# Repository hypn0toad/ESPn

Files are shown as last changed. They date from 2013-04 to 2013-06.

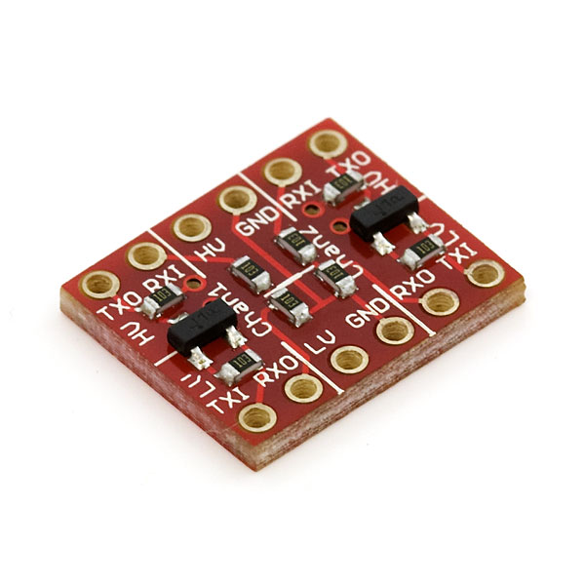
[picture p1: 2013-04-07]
docs/datasheets/Logic Level Converter Sparkfun/08745-03-L.jpg

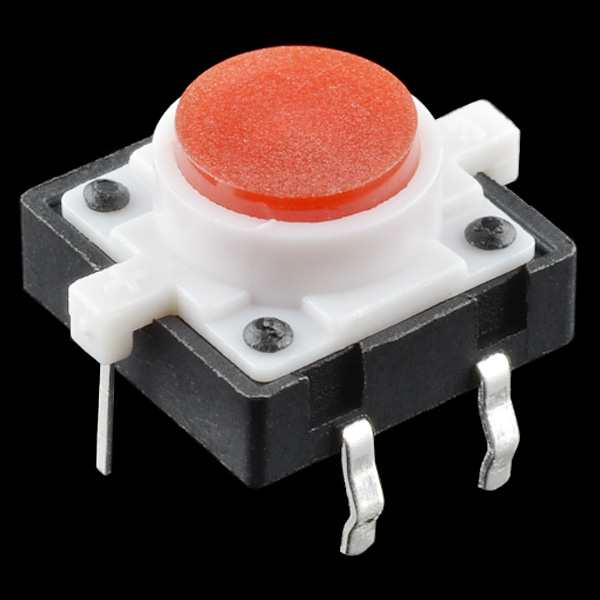
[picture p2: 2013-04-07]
docs/datasheets/LED Button/10442-01.jpg

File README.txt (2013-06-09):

This project consists of a multi platform communication device that was intended to be used as a gift / could be considered an art project. 

arduino_main/    = the main arduino code for the devices
arduino_slave/   = test code to be used in a prototype system. allows a serial interface on the PC (uart) to communicate through the arduino back and forth from an imp
imp/            = the imp code, needs to be loaded in the planner to both imps
docs/           = partslist/BOM, pinout reference, issue tracking (future ideas & bugs)
docs/datasheets = random datasheets for parts used in the design
docs/schematics = schematic and PWB for main board; schematic for logic level slave board

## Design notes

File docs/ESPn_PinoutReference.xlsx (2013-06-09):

Arduino | Description | Direction
0 | Rx, From Imp's TX | Input
1 | Tx, From Imp's RX | Output
2 | Red Button | Input
3 | Green Button | Input
4 | Standalone Gr LED | Output
5 | Online status (output from Imp, input to arduino, connects through Red Button LED) | Input
6 | Speaker | Output
7 | Green Button LED | Output
8 | Standalone Yellow LED | Output
9 | OLED MOSI | Output
10 | OLED CLK | Output
11 | OLED DC | Output
12 | OLED CS | Output
13 | OLED RESET | Output
14 | Switch 1 | Input
15 | Switch 5 | Input
16 | Switch 6 | Input
17 | Switch 7 | Input
Switch
1 | Arduino D14 (future use)
2 | Imp 8
3 | NC
4 | Imp 1
5 | Arduino D15 (future use)
6 | Arduino D16 (identity select)
7 | Arduino D17 (debug I/O)
8 | NC
Imp | Description | Direction
1 | Switch 4 (future use, but doesn't really work) | Input
2 | WiFi Status (ctrls LED and goes to Arduino) | Output
5 | UART Tx | Output
7 | UART Rx | Input
8 | Switch 2 (future use, works great) | Input
9 | NC / Pad

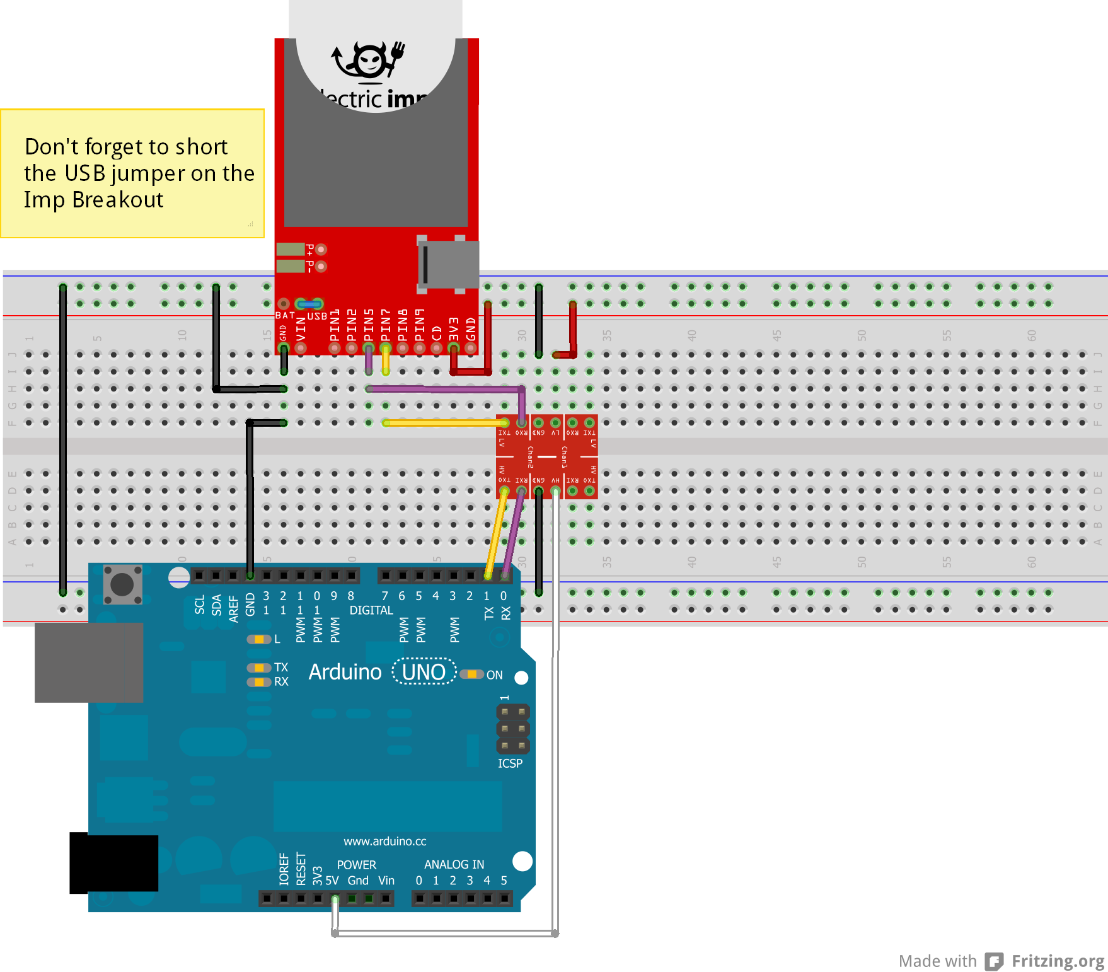
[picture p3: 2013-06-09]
docs/datasheets/Logic Level Converter Sparkfun/logic_level_connection-fritzing_schematic.png

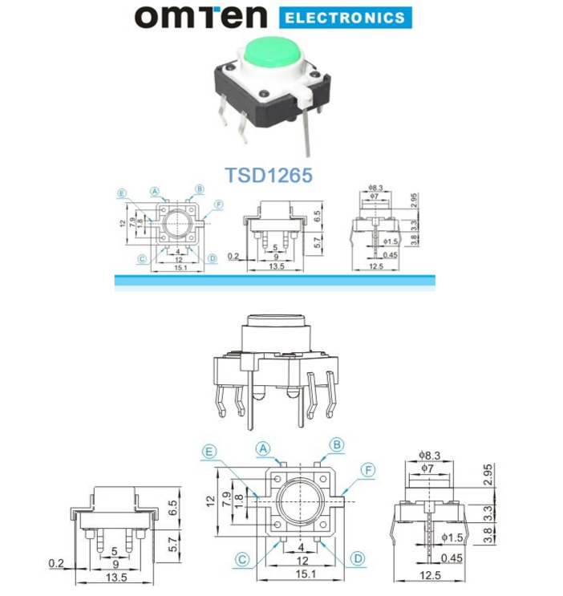
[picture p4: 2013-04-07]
docs/datasheets/LED Button/TSD1265.png

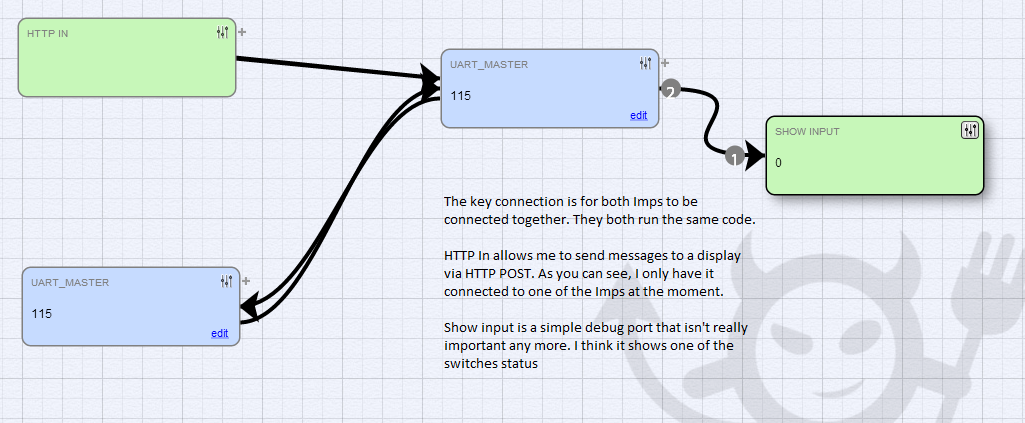
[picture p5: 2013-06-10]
imp/imp_planner.PNG

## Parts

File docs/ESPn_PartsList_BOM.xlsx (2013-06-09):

Item | Qty | Part Number | Mfg | Description | Distributor | Total Cost
1 | 1 | DEV-11114 | Sparkfun | Arduino Pro Mini 3.3V | Sparkfun | $10.00
2 | 1 | BOB-11400 | Sparkfun | Electric Imp Breakout | Sparkfun | $12.95
3 | 1 | WRL-11395 | Electric Imp | Electric Imp | Sparkfun | $30.00
4 | 1 | 938 | Adafruit | 1.3" OLED 128x64 Display | Adafruit | $24.50
5 | 1 | PS1240P02BT | TDK | Piezoelectric Buzzer | Adafruit | $1.50
6 | 1 | PRT-00119 | CUI | DC Jack Barrel Connector | Sparkfun | $1.25
7 | 1 | LD1117V33 | STMicro | 3.3V Regulator | Sparkfun | $1.95
8 | 2 | P975-ND | Unknown | 10uF Radial Lead Capacitor | Digikey | $0.46
9 | 1 | COM-08034 | China | DIP Switch Bank | Sparkfun | $1.50
10 | 1 | COM-10442 | China | Tactile LED PTH Button- Red | Sparkfun | $1.95
11 | 1 | COM-10440 | China | Tactile LED PTH Button- Green | Sparkfun | $1.95
12 | 2 | None | China | LEDs (one Gr one Ye) 5mm | Ebay - ics_shop | $0.17
13 | 4 | None | China | 0805 330ohm Resistors | Ebay - zjwhsd | $0.02
14 | 8 | None | China | 0805 10kohm Resistors | Ebay - zjwhsd | $0.03
15 | 2 | None | China | Tons Female and Male DC Headers | Ebay - ics_shop | $4.00

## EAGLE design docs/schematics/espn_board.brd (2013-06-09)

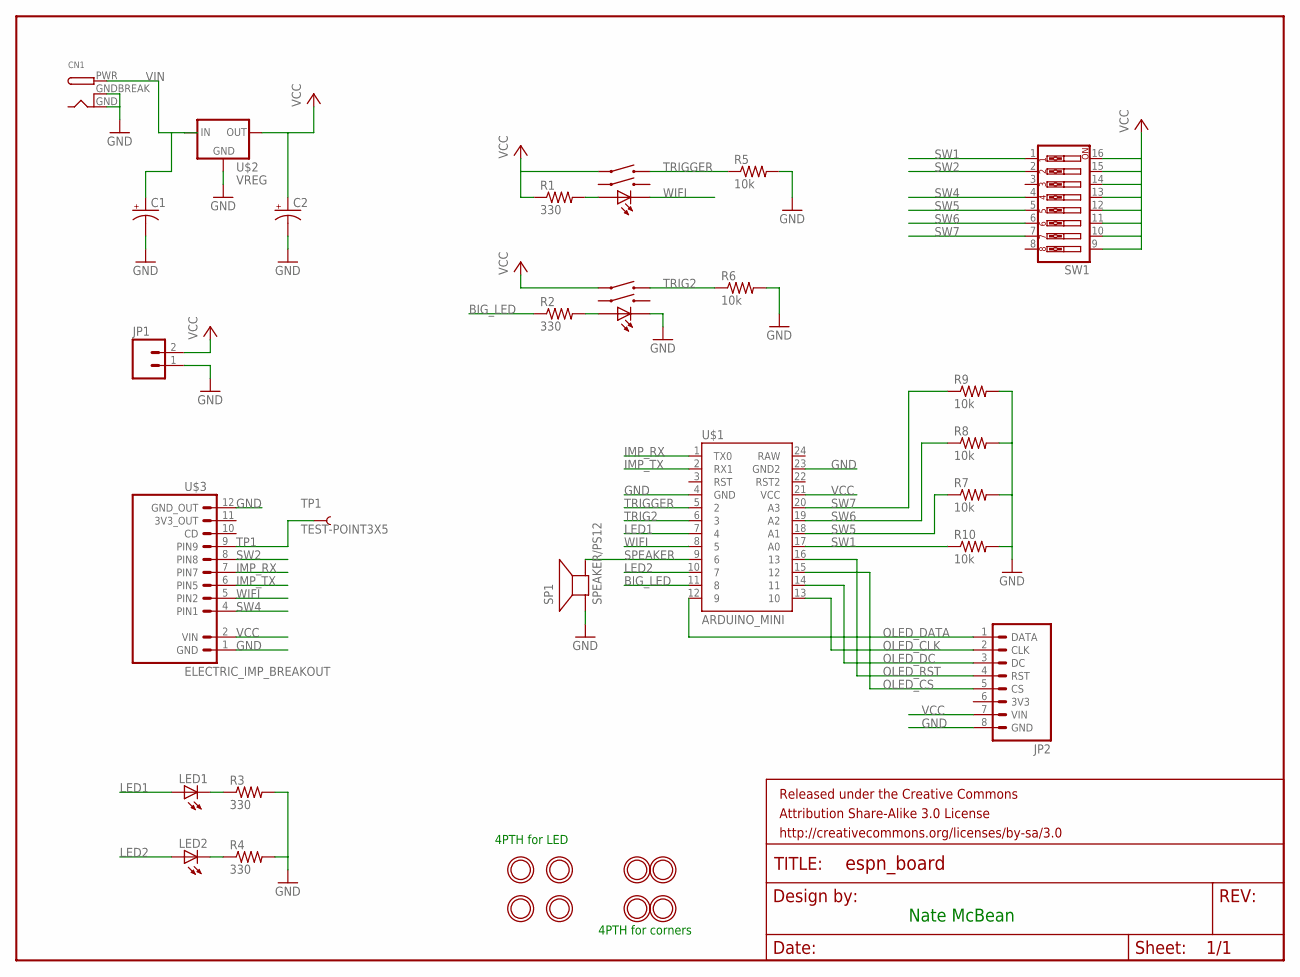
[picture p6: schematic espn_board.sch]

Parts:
ACK: LED_TACTILE_BUTTON
C1, C2: CAP_POLPTH2; CPOL-RADIAL-10UF-25V
CN1: DCBARRELPTH; DCJACK_2MM_PTH
FRAME1: FRAME-LETTER; CREATIVE_COMMONS
JP1: M02PTH; 1X02
JP2: OLED128X641X08; OLED_128X64
LED1, LED2: LED5MM
R1, R2, R3, R4: 330; R0805
R5, R6, R7, R8, R9, R10: 10k; R0805
SEND: LED_TACTILE_BUTTON
SP1: SPEAKER/PS12; PS12
SW1: SW_DIP-8; DIPSWITCH-08
TP1: TEST-POINT3X5; PAD.03X.05
U$1: ARDUINO_MINI
U$2: VREG; 78XXL
U$3: ELECTRIC_IMP_BREAKOUT
U$5, U$6, U$7, U$8, U$9, U$10, U$11, U$12: MOUNTINGHOLE2.5; MOUNTINGHOLE_2.5_PLATED

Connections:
BIG_LED: R2.1, U$1.11 (8)
GND: ACK.LEDC, C1.2 (-), C2.2 (-), CN1.GND, CN1.GNDBREAK, JP1.1, JP2.8 (GND), R3.2, R4.2, R5.2, R6.2, R7.2, R8.2, R9.2, R10.2, SP1.P$1 (+), U$1.4 (GND), U$1.23 (GND2), U$2.IN (GND), U$3.1 (GND), U$3.12 (GND_OUT)
IMP_RX: U$1.1 (TX0), U$3.7 (PIN7)
IMP_TX: U$1.2 (RX1), U$3.6 (PIN5)
LED1: LED1.A, U$1.7 (4)
LED2: LED2.A, U$1.10 (7)
unnamed: R1.2, SEND.LEDA
unnamed: ACK.LEDA, R2.2
unnamed: LED1.K (C), R3.1
unnamed: LED2.K (C), R4.1
OLED_CLK: JP2.2 (CLK), U$1.13 (10)
OLED_CS: JP2.5 (CS), U$1.15 (12)
OLED_DATA: JP2.1 (DATA), U$1.12 (9)
OLED_DC: JP2.3 (DC), U$1.14 (11)
OLED_RST: JP2.4 (RST), U$1.16 (13)
SPEAKER: SP1.P$2 (-), U$1.9 (6)
SW1: R10.1, SW1.1, U$1.17 (A0)
SW2: SW1.2, U$3.8 (PIN8)
SW4: SW1.4, U$3.4 (PIN1)
SW5: R7.1, SW1.5, U$1.18 (A1)
SW6: R8.1, SW1.6, U$1.19 (A2)
SW7: R9.1, SW1.7, U$1.20 (A3)
TP1: TP1.P$1, U$3.9 (PIN9)
TRIG2: ACK.SWA2, R6.1, U$1.6 (3)
TRIGGER: R5.1, SEND.SWA2, U$1.5 (2)
VCC: ACK.SWA1, C2.1 (+), JP1.2, JP2.7 (VIN), R1.1, SEND.SWA1, SW1.9, SW1.10, SW1.11, SW1.12, SW1.13, SW1.14, SW1.15, SW1.16, U$1.21 (VCC), U$2.GND (OUT), U$3.2 (VIN)
VIN: C1.1 (+), CN1.PWR, U$2.OUT (IN)
WIFI: SEND.LEDC, U$1.8 (5), U$3.5 (PIN2)

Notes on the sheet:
Nate McBean
4PTH for LED
4PTH for corners

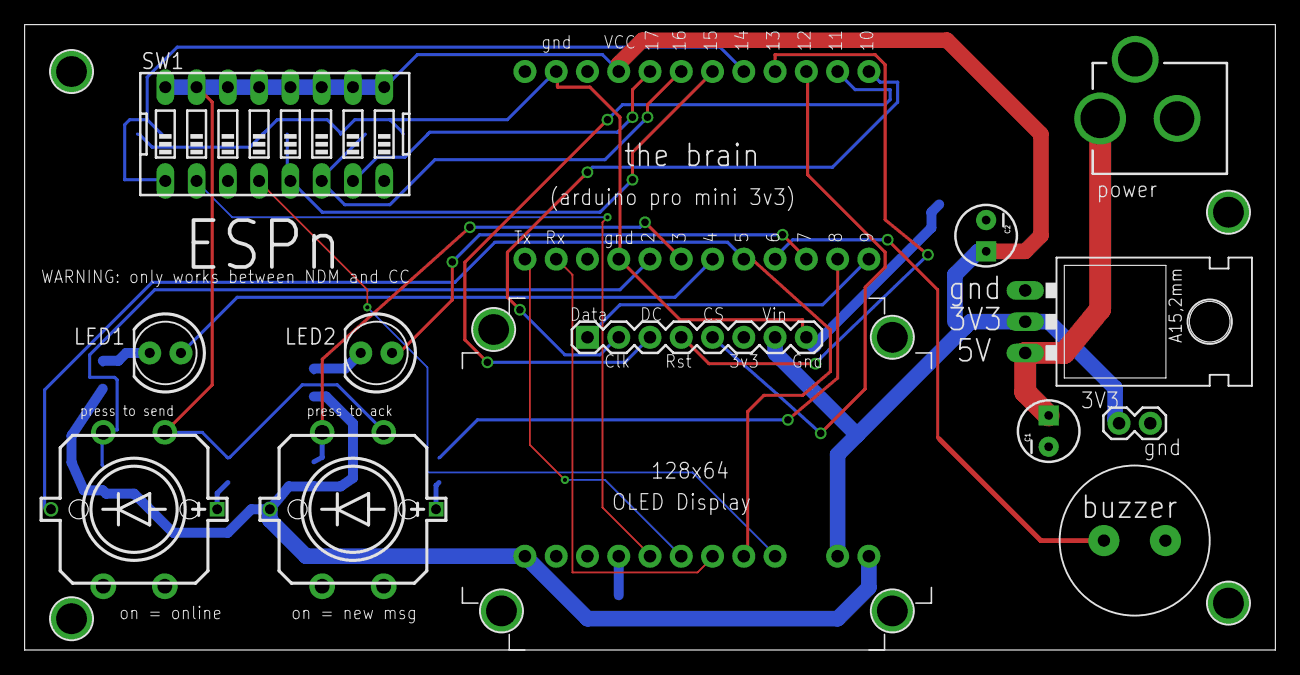
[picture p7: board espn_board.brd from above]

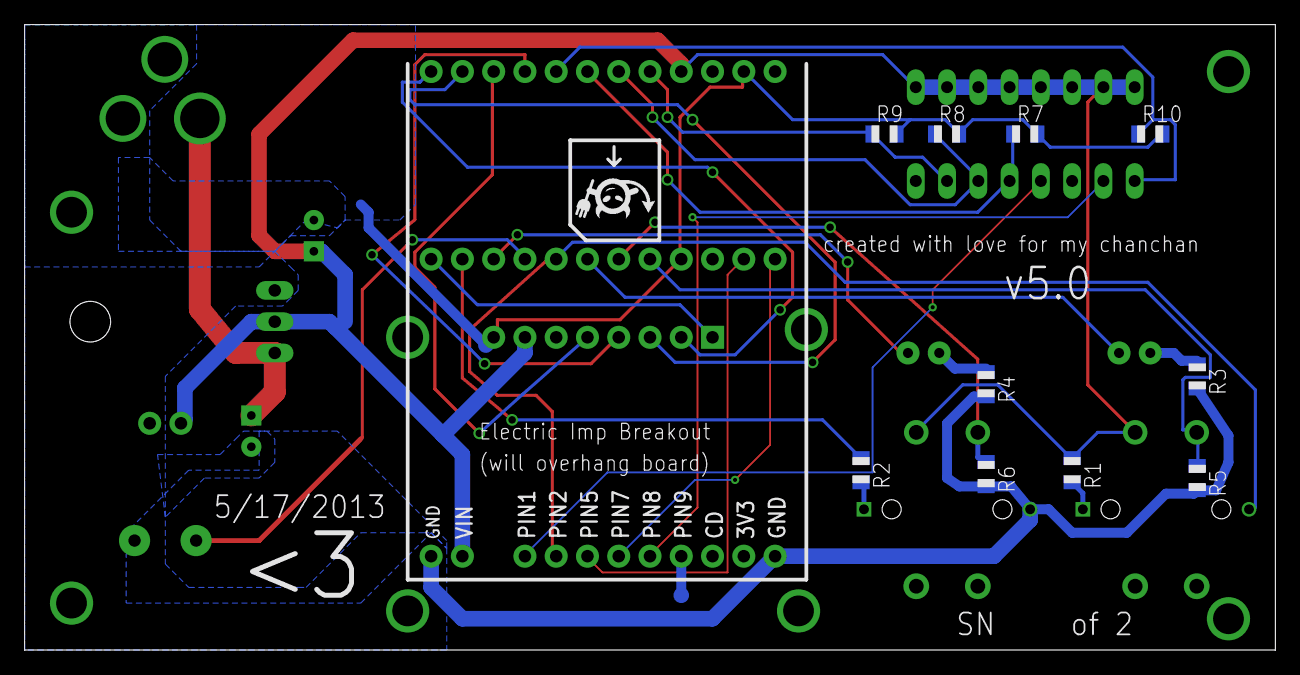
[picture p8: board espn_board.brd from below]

Board: 2 copper layers, 101.6 x 50.8 mm, 34 parts (12 on the bottom side), 28 nets.

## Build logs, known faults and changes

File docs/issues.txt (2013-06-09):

Here is a list of current issues with the design / possible improvements currently being considered. Really there weren't any huge issues, everything suprisingly worked without any sort of jumper wires or reprogramming.

PART SELECTION
- IMPROVEMENT: It would be nice to get rid of the April/Breakout Imp board. Not worth it to design custom for 2, but there arent many components that would be needed.

MECHANICAL DESIGN
- DEFECT: Holes for the OLED display are all incorrect. First off I borked the dimensions of the display and it unintentionally hangs off the bottom of the board. Secondly, the holes are the right size, but are in no way in the right space. It would be much better if these aligned. There needs to be some sort of support at the bottom. Instead of increasing board size, I would probably just not try to align the holes, and put a couple at the footer to add support for the display.

ELECTRCIAL DESIGN
- DEFECT: Red ButtonLED is much brighter than the Green ButtonLED. I suspect this is because of two reasons. First off, the Red LED is being driven via current sinking so it might be able to get more current. Secondly, I matched the resistances for the two LEDs even though they're different wavelengths. Different resistance values would probably also fix the mismatch but honestly it is more nitpicky and fine to deal with.
- DEFECT: Switch 4 doesn't correctly communicate with the Imp. I suspect this is a problem with the imp where that input isn't as flexible but the electronics are similar to that of switch 2, so I don't think its a big deal (especially since I'm not using the second switch).
- ANNOYANCE: It would be nice to have a power switch to disconnect all power from (1) the wall supply and (2) the arduino. Currently, I have to unplug the Imp when reprogramming the Arduino over the FTDI cable (it will try to draw too much current and will keep rebooting the board)

SOFTWARE
- DEFECT: TODO- fix handling of overflow for millis(). Right now I am betting on a power cycle every 40 days.
- IMPROVEMENT: use Progmem/EEPROM to store list of messages. That way I can have more variety and not run out of memory and get glitchy strings. I can also save settings between power cycles.
- IMPROVEMENT: expand to a second message type {} used for secondary string display to give variety. This would allow the internet/imp to do string management and would not make me have to deal with idiotic memory limitations of a microcontroller.
- IMPROVEMENT: loading bar at startup. didn't do this because of stupid string limitations
- IMPROVEMENT: change message triggering to interrupt functionality (thats why i picked pins 2 and 3 after all, but everything seemed to work with my lazy method)
- IMPROVEMENT: add phone interface
- IMPROVEMENT: Read receipt? with green button?
- IMPROVEMENT: Offline mode- as much as i like the electric imp, i have to be able to survive without the internet for futureproofing

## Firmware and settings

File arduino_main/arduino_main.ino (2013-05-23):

/*********************************************************************
  ESPn
  extrasensory perception via a network
  
  utilizing an arduino pro, a 128x64 OLED SPI display,
  an electric imp (and electric imp breakout board) and some accessories
 
  
  Revision Log
  Date       |Author     |Description
  -----------|-----------|-------------------------------------------
  03/31/2013  N. McBean   Initial Release- screen and piezo buzzer
  04/01/2013  N. McBean   Takes UART from the computer and displays
                            it on the OLED Display
  04/01/2013  N. McBean   Takes UART from the CLOUD (e-imp) and displays
                            it on the OLED Display O_o (matches with 
                            UART_Basic (V1) prog. pin5 imp to pin0 arduino
  04/02/2013  N. McBean   Added beep function. Added countown and 
                            rectangle bar drawing
  04/28/2013  N. McBean   Added specific pins for PWB. Tested board 
                            (all good!)
  05/05/2013  N. McBean   Changed communication protocol, now 
                            displays on screen when receive [], otherwise
                            handle each character individually.
                            Initial communication works with button press
                            TODO: debounce? needed? EDIT: nope. slow 'nuf
  05/06/2013  N. McBean   Changed string management to be char arrays.
                             i think my memory was getting garbage collected
                             and all messed up! boo! This works mostly though
                             bug- strings cant start with numbers. imp issue?
                             Also have LED indicator for long time since tx
                             Also have on screen reflection of ages. 
  05/07/2013  N. McBean   Changed LED1 & LED2 to display happy/stingy.
  05/08/2013  N. McBean   Ugh! Such limited memory. Todo: use PROGMEM
        v1.0                for now, reduce strings. 
  05/09/2013  N. McBean   Added some extra clearing triggers.
        v1.1

******************************************************************/

/*** library includes ***/
// OLED Display
#include <Wire.h>
#include <Adafruit_GFX.h>
#include <Adafruit_SSD1306.h>

/*** debug switches and settings ***/
String revID = "v1.1";
int  comm_frequency          = 21;    // how frequently we should ping the other device
int  screen_update_freq      = 1;     // how frequently should we update the screen
int  max_age_rx_comm         = 30;    // LED turns off when comm > this timeout
long age_for_low_tx          = 43200; // 12 hours since tx? complain!43200
long age_for_low_rx          = 43200; // 12 hours since rx? ensadden!


/*** pin definitions ***/
#define OLED_DC         11
#define OLED_CS         12
#define OLED_CLK        10
#define OLED_MOSI       9
#define OLED_RESET      13
#define SPEAKER_PIN     6
#define WIFI_STATUS_PIN 5

#define LED1_PIN    4
#define LED2_PIN    7
#define ACK_LED_PIN 8
#define TX_BUT_PIN  2
#define ACK_BUT_PIN 3
#define SW1_PIN     14
#define SW5_PIN     15
#define SW6_PIN     16
#define SW7_PIN     17

/*** global creations ***/
Adafruit_SSD1306 display(OLED_MOSI, OLED_CLK, OLED_DC, OLED_RESET, OLED_CS);

#if (SSD1306_LCDHEIGHT != 64)
#error("Height incorrect, please fix Adafruit_SSD1306.h!");
#endif

boolean stringComplete = false;  // whether the string is complete
unsigned long last_screen_update;

// internal stuff
boolean flash_led_status;
boolean debugio;
boolean current_identity; // 0 = c, 1 = n
boolean receiving_message;

// these boolean values are auto-updated and are based on timestamps and timeouts
boolean other_person_online, stingy_mode, happy_mode;

unsigned long last_tx_timestamp,      last_rx_timestamp;
unsigned long last_ping_tx_timestamp, last_ping_rx_timestamp;
unsigned long this_second;
char inputString[42];         // a string to hold incoming data 21 chars per line, 8 lines on size1
char oled_string[42];
int  inputString_index;

/*** initialization and setup ***/
void setup()   {                
  
  // by default, we'll generate the high voltage from the 3.3v line internally! (neat!)
  display.begin(SSD1306_SWITCHCAPVCC);
  display.clearDisplay();
  
  // initialize serial:
  Serial.begin(19200);
  //Serial.begin(9600);
  //while (!Serial) ;
  //Serial.println("Welcome!");
  
  // reserve 200 bytes for the inputString:
  inputString_index =0;
  
  last_screen_update = 0;
  //health = 100;
  this_second = 0;
  
  // setup communication
  last_tx_timestamp = 0;
  last_rx_timestamp = 0;
  last_ping_tx_timestamp = 0;
  last_ping_rx_timestamp = 0;
  other_person_online = false;
  stingy_mode = true;
  happy_mode  = false;
  
  // setup wifi status pin
  pinMode(WIFI_STATUS_PIN, INPUT);
  digitalWrite(WIFI_STATUS_PIN, 1);
  
  // setup other pins
  pinMode(LED1_PIN,    OUTPUT);
  pinMode(LED2_PIN,    OUTPUT);
  pinMode(ACK_LED_PIN, OUTPUT);
  pinMode(TX_BUT_PIN,  INPUT);
  pinMode(ACK_BUT_PIN, INPUT);
  pinMode(SW1_PIN,     INPUT);
  pinMode(SW5_PIN,     INPUT);
  pinMode(SW6_PIN,     INPUT);
  pinMode(SW7_PIN,     INPUT);  
  
  // initialize this to a value, it doesn't matter what it is
  flash_led_status  = true;
  // initial value is that we're not in the middle of a message.
  receiving_message = false;
  
  // read some startup values
  debugio = digitalRead(SW7_PIN);
  current_identity = digitalRead(SW6_PIN);

  // "demo mode" active
  if (digitalRead(SW5_PIN)) {
    // decrease thresholds for SHAME_LED and HAPPY_LED
    age_for_low_tx = 60;
    age_for_low_rx = 60;
  }
  
  // init done
  display.setTextSize(2);
  display.setTextColor(WHITE);
  display.setCursor(40,8);
  display.println("ESPn");
  
  display.setTextSize(1);
  display.setCursor(20,25);

  if ( current_identity ) {
    display.println("  Hello Nate!");     
  } else {
    display.println("Hello Christine!");     
  }

  display.setCursor(50,55);
  display.println(revID);
  display.display();

  // seed our random number generator (uses pin 5 which is NC)
  randomSeed(analogRead(5));

  //msg_class = 1;
  //msg_index = random(msg_health_low_len+1);
  
  delay(5000);
}

/*** never ending main loop ***/
// this does all of the main processing, but is specially crafted so that it should hopefully take 
// as close to zero time as possible. sure serial communication will eat up some time, but most events
// are essentially scheduled (checking timestamps), there should not be any delays in this code
void loop() {
  this_second = floor(millis()/1000);

  // first see if we've received any serial communication (this would be from the IMP).
  // this input will be decoded to see if it is part of a message, or just a command
  if(Serial.available() > 0)
  {
    // get the new byte (we receive one byte/character at a time)
    char inChar = (char)Serial.read();
    
    switch (inChar) {
      // check for starting character (this allows plaintext to be displayed)
      case '[':
        receiving_message = true;
        break;
      // check for ending character
      case  ']':
        stringComplete    = true;
        receiving_message = false;
        break;
      // any other character- advanced handle
      default:
        // if in the middle of a message, save the character
        if (receiving_message) { 
          inputString[inputString_index] = inChar;
          inputString_index++;
        // otherwise, decode the COMMAND character
        } else {
          switch (inChar) {
            // t = trigger = someone pressed the button on the other device
            case 't':
               //health = 100;
               last_rx_timestamp = this_second;
               beep();
               break; 
            // s = status = automatic ping from the other device
            case 's':
              last_ping_rx_timestamp = this_second;
              break;
            case 'x':
              last_ping_rx_timestamp = 0;
              break;
            case 'z':
              last_ping_tx_timestamp = 0;
              break;
          }
        } 
    }
  }

  // check if we should ping the server
  if ((this_second > last_ping_tx_timestamp + comm_frequency) | (last_ping_tx_timestamp == 0)) {
    Serial.print("s"); 
    last_ping_tx_timestamp = this_second;
  }
  
  // check for button press
  if (digitalRead(TX_BUT_PIN)) {
    last_tx_timestamp = this_second;
    beep();
    Serial.print("t"); 
  }  
  
  // if we just received a message, handle it.
  if (stringComplete) {
    //health = 100;
    for(int i = 0 ; i < inputString_index; i++) {
      oled_string[i] = inputString[i];
    }
    oled_string[inputString_index] = '\0';

    updateScreen();
    
    // maintenance for the next loop
    //Serial.println(inputString); 
    
    // clear the string:
    inputString_index = 0;
    stringComplete = false;
    
    beep();
  }

  // update the OLED display once a second (meh doesn't need to be faster)
  if(this_second > last_screen_update + screen_update_freq) {
    // if (health >= 5) {
    //   health -= 5; 
    // }
    updateScreen();
  }
}

/* Helper function, beeps 3 times */
void beep() {
  int delayms = 50;
  
  analogWrite(SPEAKER_PIN, 20);      // Almost any value can be used except 0 and 255
  delay(delayms);                    // wait for a delayms ms
  analogWrite(SPEAKER_PIN, 0);       // 0 turns it off
  delay(delayms);                    // wait for a delayms ms   
  
  analogWrite(SPEAKER_PIN, 20);      // Almost any value can be used except 0 and 255
  delay(delayms);                    // wait for a delayms ms
  analogWrite(SPEAKER_PIN, 0);       // 0 turns it off
  delay(delayms);                    // wait for a delayms ms 
  
  analogWrite(SPEAKER_PIN, 20);      // Almost any value can be used except 0 and 255
  delay(delayms);                    // wait for a delayms ms
  analogWrite(SPEAKER_PIN, 0);       // 0 turns it off
  delay(delayms);                    // wait for a delayms ms   
}

void updateScreen() {
  // first check wifi
  int wifi_not_connected = digitalRead(WIFI_STATUS_PIN);
  
  // temporarily comment out this code to save some valuable SRAM
  if( debugio ) {
    // // Blink some LEDs
    // digitalWrite(LED1_PIN, flash_led_status);
    // digitalWrite(LED2_PIN, flash_led_status);
    // digitalWrite(ACK_LED_PIN, flash_led_status);
    // flash_led_status = !flash_led_status;
    
    // display.clearDisplay();
    // display.setCursor(0,0);
    // display.print("Elapsed: ");
    // display.println(this_second);
    
    // display.print("Trig Button: ");
    // display.println(digitalRead(TX_BUT_PIN));
    // display.print("Ack Button : ");
    // display.println(digitalRead(ACK_BUT_PIN));   
    
    // display.print("SW1: ");
    // display.println(digitalRead(SW1_PIN));
    // display.print("SW5: ");
    // display.println(digitalRead(SW5_PIN));
    // display.print("SW6: ");
    // display.println(digitalRead(SW6_PIN));
    // display.print("SW7: ");
    // display.println(digitalRead(SW7_PIN));
  } else {
    // display it
    display.clearDisplay();
    display.setTextSize(1);
    

    // first line = wifi status
    display.setCursor(115,0);
    if(wifi_not_connected) {
      display.print(":(");
    } else if (other_person_online) {
      display.print("XD");
    } else {
      display.print(":)");
    }

    display.setCursor(0,9);
    // first line = love age
    if(last_rx_timestamp != 0) {
      unsigned long delta = this_second-last_rx_timestamp;
      display.print("Last rx ");
      if( delta > 3600) {
        display.print(delta/3600);
        display.print('h');
      } else if (delta > 60) {
        display.print(delta/60);
        display.print('m');
      } else {
        display.print(delta);
        display.print('s');
      }
      display.println(" ago");
    }

    // second line = last sighting (optional) 
    // IF haven't seen yet- complain!
    // IF haven't seen recently- display last sighting!
    // else shh, the progress bar shows this information
    if(last_ping_rx_timestamp == 0) {
      display.print("Can't find ");
      display.println(current_identity?"chanchan!":"maido!");
    } else if (!other_person_online) {
        display.print("Saw ");
        display.print(current_identity?"her ":"him ");
        display.print(this_second-last_ping_rx_timestamp);
        display.println("s ago!");
    } else {
      if(happy_mode && stingy_mode && other_person_online ) {
        display.println("All good-Share love!");
      } else if (happy_mode) {
        display.println("Sensing ample love!");
      } else {
        display.println("Fuel nearing empty!");
      }
    }

    // 4th line message if there is one
    display.setCursor(0,40);
    display.println(oled_string);
    
    display.drawRect(5,59,118,5,WHITE);
    
    //float width = 1.18*health;
    float rxhealth;
    if(last_ping_rx_timestamp==0) {
      rxhealth = 0;
    } else {
      float rxdiff, rxmax, rxdiv;
      rxdiff = this_second-last_ping_rx_timestamp;
      rxmax  = max_age_rx_comm;
      rxdiv = rxdiff/rxmax;
      rxhealth = 118 * (1-rxdiv);
    }
    float width = rxhealth;
    display.fillRect(5,59,ceil(width),5,WHITE);
  }
    
  display.display();
  last_screen_update = this_second;

  /*** update boolean values ***/
  // update the OTHER PERSON PRESENT indicator
  if ( (this_second > last_ping_rx_timestamp + max_age_rx_comm) || (last_ping_rx_timestamp == 0)) { 
    other_person_online = false;
    digitalWrite(ACK_LED_PIN,0);
  } else {
    other_person_online = true;
    digitalWrite(ACK_LED_PIN,1);
  }

  // initiate SHAME_LED when haven't txed in TX_AGE
  if( (last_tx_timestamp == 0) || this_second > (last_tx_timestamp + age_for_low_tx)) {
    stingy_mode = true;  
    digitalWrite(LED2_PIN,1);
  } else {
    stingy_mode = false;
    digitalWrite(LED2_PIN,0);
  }

  
  // initiate HAPPY_LED when have rx'ed in RX_AGE
  if ((last_rx_timestamp == 0) || this_second > (last_rx_timestamp + age_for_low_rx)) {
    happy_mode = false;
    digitalWrite(LED1_PIN,0);
  } else {
    happy_mode = true;
    digitalWrite(LED1_PIN,1);
  }  
}

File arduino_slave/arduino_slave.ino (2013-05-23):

/*********************************************************************
  ESPn
  extrasensory perception via a network
  
  utilizing an arduino pro, a 128x64 OLED SPI display,
  an electric imp (and electric imp breakout board) and some accessories
 
  
  Revision Log
  Date       |Author     |Description
  -----------|-----------|-------------------------------------------
  04/05/2013  N. McBean   Initial Release based on other code
                            this code will interact with the serial
                            terminal. Used as a test board to send 
                            and receive signals from the other board
  04/07/2013 N. McBean    Will receive messages from the imp and 
                            print them in the serial console. Will
                            send messages to the imp when typed.
******************************************************************/

/*** library includes ***/
// OLED Display
#include <Wire.h>
#include <Adafruit_GFX.h>
#include <Adafruit_SSD1306.h>

/*** pin definitions ***/
#define OLED_DC     11
#define OLED_CS     12
#define OLED_CLK    10
#define OLED_MOSI   9
#define OLED_RESET  13
#define SPEAKER_PIN 6
#define TRIGGER_PIN 2

/*** global creations ***/
Adafruit_SSD1306 display(OLED_MOSI, OLED_CLK, OLED_DC, OLED_RESET, OLED_CS);

#if (SSD1306_LCDHEIGHT != 64)
#error("Height incorrect, please fix Adafruit_SSD1306.h!");
#endif

String inputString = "";         // a string to hold incoming data 21 chars per line, 8 lines on size1
String oled_string = "";
boolean stringComplete = false;  // whether the string is complete
unsigned long last_screen_update;
unsigned long last_communication_timestamp;
unsigned long last_communication_age;
String console_input = "";
boolean consoleComplete = false;
int health;

volatile int trigger_button_pushed = 0;
unsigned long last_trigger;


/*** initialization and setup ***/
void setup()   {                
  /**********************************************************************************/
  /* setup display */
  display.begin(SSD1306_SWITCHCAPVCC);
  display.clearDisplay();
  display.setTextSize(1);
  display.setTextColor(WHITE);
  display.setCursor(0,0);
  display.println("Powering up...");
  display.display();

  /**********************************************************************************/  
  /* setup serial */
  Serial1.begin(19200);
  Serial.begin(9600);
  //while (!Serial) ;
  Serial.println("Welcome!");
  
  // reserve 200 bytes for the inputString:
  inputString.reserve(200);
  oled_string.reserve(200);
  console_input.reserve(200);
  
  last_screen_update = 0;
  health = 100; 

  /**********************************************************************************/
  /* send a dummy message to the imp */
  Serial1.println("Auto comm from slave imp...,");
  
  /**********************************************************************************/
  /* setup trigger button */
  trigger_button_pushed = 0;
  pinMode(TRIGGER_PIN, OUTPUT);
  // this needs to be 0 because the first (0th) interrupt is on pin 2
  // THE STUPID LEONARDO MESSED UP NUMBERING- pin 3 = int 0
  // use PIN3 on the leonardo. use PIN2 on the pro ugh.
  attachInterrupt(0,trigger_push, RISING);
  last_trigger =0;  
}

// we hit the trigger! don't do serial operations in here. get out ASAP
// (from the documentation "Inside the attached function, delay() won't work and the 
// value returned by millis() will not increment. Serial data received while in the 
// function may be lost. You should declare as volatile any variables that you modify 
// within the attached function.

void trigger_push () {
  trigger_button_pushed = 1; 
}

/*** never ending main loop ***/
void loop() {
  
  // read from the console
  if(Serial.available() > 0)
  {
    char inChar = (char)Serial.read();

    // if the incoming character is a newline, set a flag
    // so the main loop can do something about it:
    if (inChar == '~') {
      consoleComplete = true;
    } else {
      // add it to the inputString:
      console_input += inChar;
    }
  }
  
  // if finished reading from teh console, send it to the imp (and print to console)
  if (consoleComplete) {
    // print to the console
    Serial.print("tx to imp: ");
    Serial.println(console_input);
    
    // send to the imp
    Serial1.println(console_input); 
   
    consoleComplete = false;
    console_input = "";
  }
  
  // read fromt he imp
  if(Serial1.available() > 0)
  {
    // get the new byte:
    char inChar = (char)Serial1.read();

    // if the incoming character is a newline, set a flag
    // so the main loop can do something about it:
    if (inChar == ',') {
      stringComplete = true;
    } else {
      // add it to the inputString:
      inputString += inChar;
    }
    
  }

  // if finished reading from the imp, send it to the console
  // print the string when a newline arrives:
  if (stringComplete) {
    health = 100;
    oled_string = inputString;
    updateScreen();
    
    // maintenance for the next loop
    Serial.print("rx from imp: ");
    Serial.println(inputString); 
    
    // clear the string:
    inputString = "";
    stringComplete = false;
    
    beep();
  }
  
  // update the screen every second
  if(millis() > last_screen_update + 1000) {
    if (health >= 5) {
      health -= 5; 
    }
    updateScreen();
  }
  
  // handle the button presses here
  if( trigger_button_pushed && millis() > last_trigger + 1000) {
    trigger_button_pushed = 0;
    Serial.println("Sending trigger!");
    // temporarily keep using the comma delimiter
    // soon will just send the one char
    Serial1.print("s,");
    last_trigger = millis();
  } else if ( trigger_button_pushed ) {
    // oh no! we bounced!
    // kill the spare
    trigger_button_pushed = 0; 
  }
}

/* Helper function, beeps 3 times */
void beep() {
  int delayms = 50;
  
  analogWrite(SPEAKER_PIN, 20);      // Almost any value can be used except 0 and 255
  delay(delayms);                    // wait for a delayms ms
  analogWrite(SPEAKER_PIN, 0);       // 0 turns it off
  delay(delayms);                    // wait for a delayms ms   
  
  analogWrite(SPEAKER_PIN, 20);      // Almost any value can be used except 0 and 255
  delay(delayms);                    // wait for a delayms ms
  analogWrite(SPEAKER_PIN, 0);       // 0 turns it off
  delay(delayms);                    // wait for a delayms ms 
  
  analogWrite(SPEAKER_PIN, 20);      // Almost any value can be used except 0 and 255
  delay(delayms);                    // wait for a delayms ms
  analogWrite(SPEAKER_PIN, 0);       // 0 turns it off
  delay(delayms);                    // wait for a delayms ms   
}
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

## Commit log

2013-04-01 Initial Release
    This just has a OLED display and a piezo buzzer connected to an arduino.
    Think of it as a "first step" program. It doesn't do anything snazzy,
    but it works!
    [arduino_maido.ino]
2013-04-02 PC UART to OLED
    Added PC UART to OLED display. Note will display when you end with the |
    character (not a newline). Also, note that the next step is to respond
    to Serial1 (on the leonardo.. on pro mini will probably be Serial) which
    should have comm from the Electric Imp.
2013-04-02 Welcome to the cloud
    Now the UART is received from the cloud (from the imp.php website form
    POST) and then is transmitted from the imp over UART to the arduino. The
    arduino then displays it just the same as if it received it from a local
    PC. Baud rate of 9600 didn't seem to work but 19200 seems fine (odd..)
    [arduino_maido.ino]
2013-04-05 Update for Arduino Pro Mini
    Received and switched code to work for an Arduino Pro Mini (Running at
    3V3). Works great! (only had to switch away from the dual serials
    available on the Leonardo)
2013-04-07 Added slave leonardo for testing purposes
    This release allows two imps to talk to each other. The sparkfun UART
    code has been upgraded to use a callback function. The slave setup will
    receive from the imp and display in a serial console. It will also
    transmit serial commands from the console out over the imp. Fully
    working checkin. Also added some datasheets and a schematic for the
    slave setup.
    [arduino_slave.fzz]
2013-04-07 Addition of online status
    Will now light up an LED from the IMP when connected to wifi. Arduino
    connects to this indicator to also know when online.
2013-04-08 Added Trigger Button
    New! Trigger button on slave arduino (well will be on master as well
    eventually). Sends an automatic serial message. "Debounced" to trigger a
    max of once a second.
2013-04-10 Initial Schematic
    All components placed. Not fully connected / board unrouted.
    [maido_board.brd, maido_board.sch]
2013-04-10 Initial Layout
    Schematic completely wired. Have initial placement (no routing)
    [maido_board.brd, maido_board.sch]
2013-04-10 Fixed pinout on OLED
    Oops! That would have been a horrible mistake. I also messed around with
    routing some.
    [maido_board.brd, maido_board.sch]
2013-04-10 Layout Work
    More work on the layout. I pretty carefully managed power to from the DC
    header to the VREG to the Imp (by FAR the biggest power consumer on the
    board). I also rearranged some parts to try to optimize placement. Next
    up- auto route.
    [maido_board.brd, maido_board.sch]
2013-04-29 Final Built Board
    Final built board schematic + layout (received board already, tested,
    works). Added IO pins to the arduino code, works.
    [maido_board.brd, maido_board.sch]
2013-05-05 Button Comms Working
    Successfully sends a message to the other device when press a button
    (switched communication protocol). Woot woot
2013-05-06 Companion Detection
    Modified timestamps to now record time in seconds (try to prevent
    overflow with the poor arduino's integers). Now the devices ping each
    other, and have a display based on system status. icon in corner
    indicates system health.
    [arduino_maido.ino]
2013-05-07 Age Tracking
    Switched to use char arrays instead of strings (strings got corrupted).
    This is more efficient anyways. Added OLED display of ages. Track ping
    (tx/rx) and regular tx/rx. Light LED when haven't txed in a while (12h).
2013-05-07 Health Bar Update
    Now health bar displays time since last status update from other device.
2013-05-09 Failure Text
    Stupid arduino having limited memory. This (when uncommented) glitched
    the poor thing like crazy. I'm committing it just so i have it in
    revision history.
    [arduino_maido.ino]
2013-05-09 Code Cleanup and Nicer Rx Age
    Rearranged some code and cleaned some stuff up. This is rev 1.0 on the
    device. Have a list of stuff to do still (oh well) but this will be
    final unless something comes up. Added more human readable RX age (h m s
    instead of just s). Looks good!
2013-06-09 Doc Additions
    Added BOM, added Pinout Reference, added issue tracking text file
    [ESPn_PartsList_BOM.xlsx, ESPn_PinoutReference.xlsx, espn_board.brd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]

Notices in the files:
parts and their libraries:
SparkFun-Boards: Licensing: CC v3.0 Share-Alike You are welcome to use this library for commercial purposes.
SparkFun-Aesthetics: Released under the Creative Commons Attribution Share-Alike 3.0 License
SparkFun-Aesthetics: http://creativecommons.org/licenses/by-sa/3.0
